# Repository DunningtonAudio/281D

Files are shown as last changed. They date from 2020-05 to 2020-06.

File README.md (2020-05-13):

# 281D
A quad function generator project

The 281D Quad Function Generator is designed to replicate the functionality of the Buchla 281 module using modern construction techniques and readily available parts. It is primarily based on the original circuit designed by Don Buchla, with the following additions/alterations:

* Improved input and mode selection circuitry – no requirement to “kick” the generators when selecting self cycle mode.
* All outputs are buffered, protecting the integrator core and passive end pulse generation from the effects of loading when stacked to multiple inputs.
* End pulse outputs are designed to allow stacking of multiple outputs to a single input without affecting cycling of individual generators, allowing the creation of complex/non-repeating/polyrhythmic pulse sequences. Unlike other solutions that simply add a diode in series with the output, the 281D end pulse outputs can drive a floating input low.
 
There are several build options to adjust the function of the module to a particular users requirements.

The repository contains:

* KiCad project files.
* Schematic and build/calibration notes as PDF files.
* Bill of Materials in ODS format.
* Interactive webpage for matching BOM items to PCB locations.

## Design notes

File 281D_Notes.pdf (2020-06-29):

281D Quad Function Generator

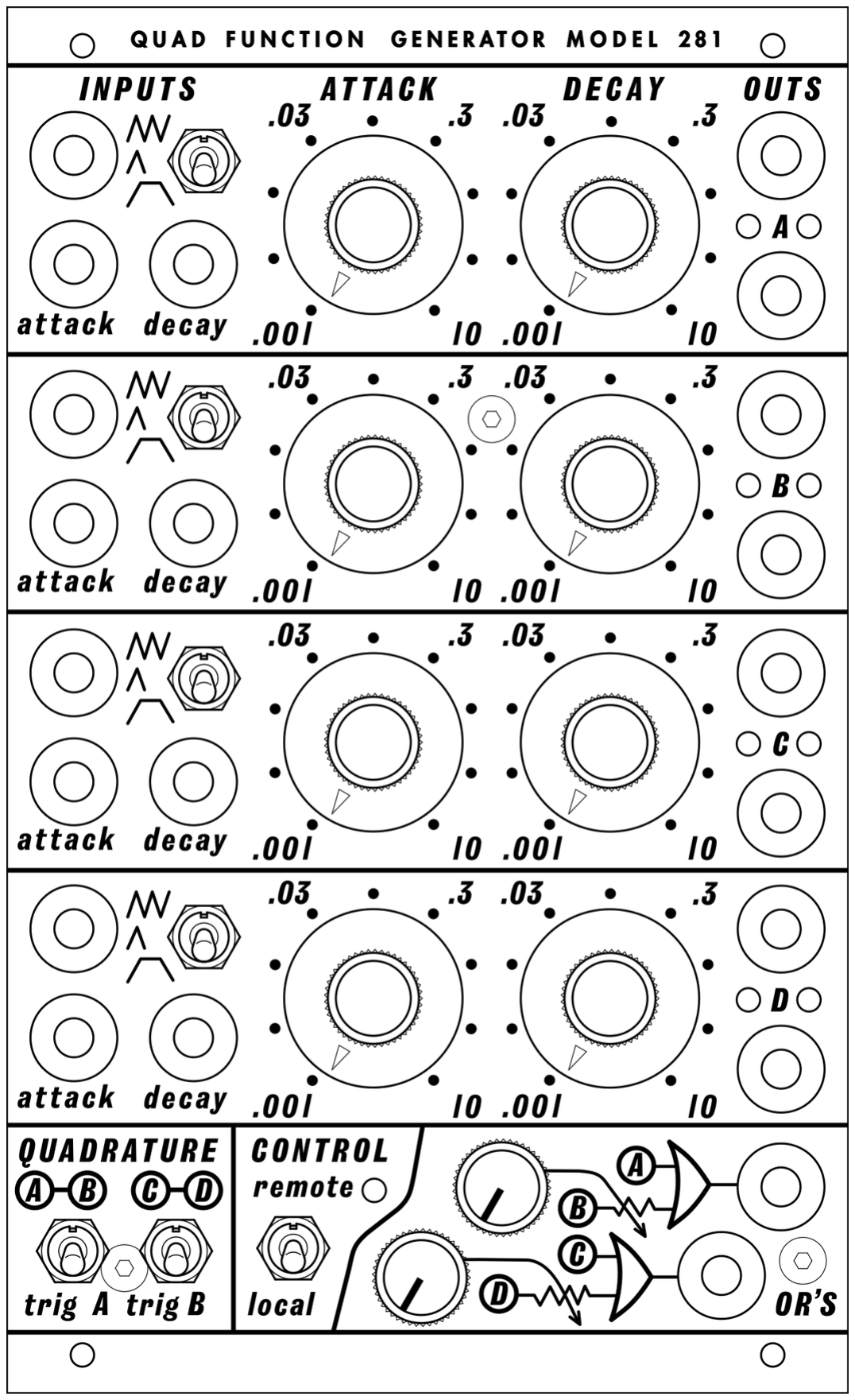
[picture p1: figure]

The 281D Quad Function Generator is designed to replicate the functionality of the Buchla 281 module using modern construction techniques and readily available parts. It is primarily based on the original circuit designed by Don Buchla, with the following additions/alterations:

- Improved input and mode selection circuitry – no requirement to “kick” the generators when selecting self cycle mode.
- All outputs are buffered, protecting the integrator core and passive end pulse generation circuit from the effects of loading when stacked to multiple inputs.
- End pulse outputs are designed to allow stacking of multiple outputs to a single input without affecting cycling of individual generators, allowing the creation of complex/non-repeating/polyrhythmic pulse sequences. Unlike other solutions that simply add a diode in series with the output, the 281D end pulse outputs can drive a floating input low.

Build Notes:

** The 281D is designed to be suitable for hand assembly, but it is not recommended as a “learn surface mount” starting point. You should at a minimum have a temperature controlled soldering iron with a reasonably fine point and good quality solder 0.5mm diameter or finer. Some form of magnification may be beneficial for placing/inspecting the SOT-363 packages. **

It is recommended that the circuit board is populated in the following order:

- SOT-363 packages (note polarity – these are not symmetrical!)
- SOT-23 packages
- SOIC packages
- 0805 passives
- Trimmer potentiometers
- Electrolytic capacitors
- Film capacitors C101,201,301,401 (Through hole pads are provided for hand assembly. If hand soldering the 2416 footprint SMT capacitors the minimum temperature/time possible should be used)
- Power wiring harness

Connectors should have their wire links attached and be mounted to the front panel, along with standoffs. Front panel potentiometers and switches can then be loosely fitted into the PCB and the panel and PCB brought together before gently tightening the potentiometer/switch fixing nuts and soldering the potentiometers and connector to PCB wires into place.

Modifications:

A standard build of the 281D uses the two-stage Buchla pulse to differentiate between the transient and sustain settings of the mode switch. If the module is to be used with standard gate signals, the following changes can be made:

- Omit or remove resistors R112,212,312,412
- Fit capacitors C199,299,399,499 (47nF 0805), diodes D199,299,399,499 (BAT54WS) and resistors R199,299,399,499 (4.7M 0805)

Calibration procedure:

Equipment required:
- Power supply delivering +/- 15V, current limit at 100mA and +12V, current limit at 20mA
- Oscilloscope (A DSO will make calibration easier)
1. Set front panel controls as follows:
- VR101/201/301/401 Attack – Fully CCW
- VR102/201/302/402 Decay – Fully CW
- VR203/403 OR Level – Fully CCW
- SW101/201/301/401 Mode – Centre/Transient
- SW102/302 Quadrature – Down
- SW1 Remote Enable – Down
2. Set all trimpots TR101,201,301,401 to halfway.
3. Apply power to the module and check for approx 85mA draw on the +15V rail and 70mA draw on the -15V rail. No current should be drawn from the 12V rail with the controls set as described above.
4. Switch function generator A into self cycle mode and monitor the CV output on the oscilloscope – it should be a 10V saw wave. Check the function of the output LED.
5. Adjust trimpot TR101 to set the fall time of the saw wave to 10 seconds.
6. Repeat steps 4 and 5 for function generators B/C/D, using trimpots TR201/301/401
7. Set front panel controls as follows:
- VR101/201/301/401 Attack – Fully CW
- VR102/201/302/402 Decay – Fully CCW
- VR203/403 OR Level – Fully CCW
- SW101/301 Mode – Up/Cycle
- SW201/401 Mode – Centre/Transient
- SW102,302 Quadrature – Up
- SW1 Remote Enable – Down
8. Check that all four quadrature LEDs are lit. The behaviour of the function generators should be as follows:
- A/C should slowly rise to their maximum amplitudes whilst B/D are idle
- Once A/C are at max, B/D will slowly rise to max
- Once B/D are at max, A/C will reset and begin to rise again, shortly followed by B/D also resetting
9. Set front panel controls as follows:
- VR101/301 Attack – Fully CW
- VR201/401 Attack – Fully CCW
- VR102/202/302/402 Decay – Fully CCW
- VR203/403 OR Level – Fully CW
- SW101/201/301/401 Mode – Up/Cycle
- SW102,302 Quadrature – Down
- SW1 Remote Enable – Down
10. Check the OR outputs on the oscilloscope – both should display a slow rise of the minimum voltage from 0V to 10V with rapidly oscillating peaks of 10V superimposed on top.
11. Check the function of the remote enable switch – the LED should illuminate in the centre and up positions of the switch and be extinguished in the down position.

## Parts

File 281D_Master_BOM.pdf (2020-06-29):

281D_Master

Reference | Quantity | Value | Footprint | Manufacturer | MPN | Supplier | Order Code | Description | Notes
PCB Mount
C102-103 C202-203 C302-303 C402-403 | 8 | 47n | C0805 | Yageo | CC0805KRX7R9BB473 | Mouser | 603-CC0805KRX7R9BB473 | X7R, 50V, 10%
C4 C6-8 C111-118 C211-213 C311-318 C411-413 | 26 | 100n | C0805 | Yageo | CC0805KRX7R9BB104 | Mouser | 603-CC0805KRX7R9BB104 | X7R, 50V, 10%
C101 C201 C301 C401 | 4 | 220n | C2416 | Panasonic | ECH-U1H224GX9 | Mouser | 667-ECH-U1H224GX9 | PPS, 50V, 2% | Alt. Fit 5.08mm THT box caps C_101, C_201, C_301, C_401
C1-3 C5 | 4 | 22u | CE5x5.8 | Panasonic | EEE-FK1V220AR | Mouser | 667-EEE-FK1V220AR | 35V, 20%, 105deg
D101 D107/207 D201 D301 D307/407 D401 | 6 | BAT54C | SOT-23-3 | On Semiconductor | BAT54CLT1G | Mouser | 863-BAT54CLT1G | Dual schottky diode common cathode
D102 D202 D302 D402 | 4 | SZMM3Z10VST1G | SOD-323 | On Semiconductor | SZMM3Z10VST1G | Mouser | 863-SZMM3Z10VST1G | Zener diode 10.2V 300mW
D103-104 D108-109 D203-204 D208 D303-304 D308-309 D403-404 D408 | 14 | BAT54WS | SOD-323 | Diodes Inc | BAT54WS-7-F | Mouser | 621-BAT54WS-F | Schottky diode 100mA
D1 D105 D205 D305 D405 | 5 | Red_3mm | 3mm LED THT | Wurth Elektronik | 151031SS04000 | Mouser | 710-151031SS04000 | LED red 3mm 635nm 160mcd
D106 D206 D306 D406 | 4 | Yel_3mm | 3mm LED THT | Wurth Elektronik | 151031YS06000 | Mouser | 710-151031YS06000 | LED yellow 3mm 590nm 110mcd
L1 L2 L3 | 3 | 10u | L0805 | Taiyo Yuden | LBC2012T100K | Mouser | 963-LBC2012T100K | 1.2R, 200mA, 10%
Q1 Q103 Q203 Q303 Q403 | 5 | MMBT3904 | SOT-23-3 | On Semiconductor | MMBT3904LT1G | Mouser | 863-MMBT3904LT1G | NPN
Q101 Q201 Q301 Q401 | 4 | DMMT3906W | SOT-363 | Diodes Inc | DMMT3906W-7-F | Mouser | 621-DMMT3906W-F | Dual Matched PNP | Note polarity – these are not symmetrical!
Q102 Q202 Q302 Q402 | 4 | MMBFJ201 | SOT-23-3 | On Semiconductor | MMBFJ201 | Mouser | 512-MMBFJ201 | N-Channel JFET
R123-124 R127 R223-224 R227 R323-324 R327 R423-424 R427 | 12 | 680R | R0805 | Yageo | RC0805FR-07680RL | Mouser | 603-RC0805FR-07680RL | 150V, 125mW, 1%, 100PPM
R110 R116 R144 R147 R153 R210 R216 R244 R247 R310 R316 R344 R347 R353 R410 R416 R444 R447 | 18 | 1k | R0805 | Yageo | RC0805FR-071KL | Mouser | 603-RC0805FR-071KL | 150V, 125mW, 1%, 100PPM
R102 R119 R129-132 R202 R219 R229-232 R302 R319 R329-332 R402 R419 R429-432 | 24 | 4k7 | R0805 | Yageo | RC0805FR-074K7L | Mouser | 603-RC0805FR-074K7L | 150V, 125mW, 1%, 100PPM
R106 R148 R206 R306 R348 R406 | 6 | 5k6 | R0805 | Yageo | RC0805FR-075K6L | Mouser | 603-RC0805FR-075K6L | 150V, 125mW, 1%, 100PPM
R1 R134 R234 R334 R434 | 5 | 6k8 | R0805 | Yageo | RC0805FR-076K8L | Mouser | 603-RC0805FR-076K8L | 150V, 125mW, 1%, 100PPM
R126 R136 R143 R146 R152 R226 R236 R243 R246 R326 R336 R343 R346 R352 R426 R436 R443 R446 | 18 | 10k | R0805 | Yageo | RC0805FR-0710KL | Mouser | 603-RC0805FR-0710KL | 150V, 125mW, 1%, 100PPM
R142 R145 R151 R242 R245 R342 R345 R351 R442 R445 | 10 | 11k | R0805 | Yageo | RC0805FR-0711KL | Mouser | 603-RC0805FR-0711KL | 150V, 125mW, 1%, 100PPM
R103 R203 R303 R403 | 4 | 15k | R0805 | Yageo | RC0805FR-0715KL | Mouser | 603-RC0805FR-0715KL | 150V, 125mW, 1%, 100PPM
R2 R128 R133 R140 R228 R233 R240 R328 R333 R340 R428 R433 R440 | 13 | 22k | R0805 | Yageo | RC0805FR-0722KL | Mouser | 603-RC0805FR-0722KL | 150V, 125mW, 1%, 100PPM
R104 R108-109 R113-114 R121 R125 R149 R204 R208-209 R213-214 R221 R225 R304 R308-309 R313-314 R321 R325 R349 R404 R408-409 R413-414 R421 R425 | 30 | 47k | R0805 | Yageo | RC0805FR-0747KL | Mouser | 603-RC0805FR-0747KL | 150V, 125mW, 1%, 100PPM
R105 R107 R115 R117 R135 R205 R207 R215 R217 R235 R305 R307 R315 R317 R335 R405 R407 R415 R417 R435 | 20 | 49k9 | R0805 | Yageo | RC0805FR-0749K9L | Mouser | 603-RC0805FR-0749K9L | 150V, 125mW, 1%, 100PPM
R101 R111-112 R138 R141 R150 R201 R211-212 R238 R241 R301 R311-312 R338 R341 R350 R401 R411-412 R438 R441 | 22 | 100k | R0805 | Yageo | RC0805FR-07100KL | Mouser | 603-RC0805FR-07100KL | 150V, 125mW, 1%, 100PPM
R122 R222 R322 R422 | 4 | 150k | R0805 | Yageo | RC0805FR-07150KL | Mouser | 603-RC0805FR-07150KL | 150V, 125mW, 1%, 100PPM
R137 R237 R337 R437 | 4 | 470k | R0805 | Yageo | RC0805FR-07470KL | Mouser | 603-RC0805FR-07470KL | 150V, 125mW, 1%, 100PPM
R139 R239 R339 R439 | 4 | 1M | R0805 | Yageo | RC0805FR-071ML | Mouser | 603-RC0805FR-071ML | 150V, 125mW, 1%, 100PPM
R118 R120 R218 R220 R318 R320 R418 R420 | 8 | 4M7 | R0805 | Yageo | RC0805FR-074M7L | Mouser | 603-RC0805FR-074M7L | 150V, 125mW, 1%, 100PPM
SW1 SW101 SW201 SW301 SW401 | 5 | SPDT_ON-OFF-ON | M201X | NKK | M2013SS1W01 | Mouser | 633-M201301 | Toggle switch SPDT On-Off-On
SW102, SW302, | 2 | SPDT_ON-ON | M201X | NKK | M2012SS1W01 | Mouser | 633-M201201 | Toggle switch SPDT On-On
TR101, TR201, TR301, TR401, | 4 | 50k | 3314J | Bourns | 3314J-1-503E | Mouser | 652-3314J-1-503E | 500V,250mW, 20%, 100PPM
U1, | 1 | L78L10 | SOT-89 | ST Microelectronics | L78L10ACUTR | Mouser | 511-L78L10ACU | Linear voltage reg 10V 100mA
U2, | 1 | TL072 | SOIC08 | Texas Instruments | TL072IDR | Mouser | 595-TL072IDR | Dual op-amp FET input
U101, U201, U105/205, U301, U401, U305/405, | 6 | TL074 | SOIC14 | Texas Instruments | TL074IDR | Mouser | 595-TL074IDR | Quad op-amp FET input
U102, U202, U302, U402, | 4 | CD4001 | SOIC14 | Texas Instruments | CD4001BM96 | Mouser | 595-CD4001BM96 | Quad NOR gate 2 input
U103/203, U303/403, | 2 | CD4066 | SOIC14 | Texas Instruments | CD4066BM96 | Mouser | 595-CD4066BM96 | Quad analogue switch SPST
U104/204, U304/404, | 2 | LM13700 | SOIC16 | Texas Instruments | LM13700MX/NOPB | Mouser | 926-LM13700MX/NOPB | Dual transconductance amplifier
VR101-102 VR201-202 VR301-302 VR401-402 | 8 | 10k Linear | RV16AF-41-(L)R1-XXX | Alpha | RV16AF-41-15R1-103B | Small Bear | 1011 B10K | 16mm RA PCB mount potentiometer
VR203 VR403 | 2 | 100k Linear | RD901F-40-00D | Alpha | RD901F-40-15R1-104B | Small Bear | 1012A B100K | 9mm RA PCB mount potentiometer
| 8 | | | Alpha | M7x0.75 | Small Bear | 1018 | Toothed washer for 16mm potentiometer | Fit between potentiometer body and panel
| 8 | | | Alpha | | Small Bear | 1011AM | Dust cover for 16mm potentiometer | Fit on all 16mm potentiometers

281D_Master

Reference | Quantity | Value | Footprint | Manufacturer | MPN | Supplier | Order Code | Description | Notes
Panel Mount
J101 J201 J301 J401 | 4 | Pulse inputs | Johnson | 108-0906-001 | Mouser | 530-108-0906-1 | Orange banana jack
J102-103 J202-203 J302-J303 J402-J403 | 8 | CV inputs | Johnson | 108-0903-001 | Mouser | 530-108-0903-1 | Black banana jack
J104 J204 J304 J404 | 4 | Pulse outputs | Johnson | 108-0902-001 | Mouser | 530-108-0902-1 | Red banana jack
J105-106 J205 J305-306 J405 | 6 | CV outputs | Johnson | 108-0910-001 | Mouser | 530-108-0910-1 | Blue banana jack
24awg wire black 25mm length | 8 | | Alpha Wire | 892419 BK005 | Mouser | 602-892419-100-02 | Wiring to CV inputs | Strip 4mm each end. Order code is for 30.5m reel
24awg wire orange 25mm length | 4 | | Alpha Wire | 892419 OR005 | Mouser | 602-892419-100-08 | Wiring to pulse inputs | Strip 4mm each end. Order code is for 30.5m reel
24awg wire red 25mm length | 4 | | Alpha Wire | 892419 RD005 | Mouser | 602-892419-100-03 | Wiring to pulse outputs | Strip 4mm each end. Order code is for 30.5m reel
24awg wire blue 25mm length | 6 | | Alpha Wire | 892419 BL005 | Mouser | 602-892419-100-06 | Wiring to CV outputs | Strip 4mm each end. Order code is for 30.5m reel
Hardware & Misc
PCB | 1 | | Dunnington Audio | | thebeast.co.uk | http://thebeast.co.uk/?product | Printed circuit board
Front panel | 1 | | The Beast | | thebeast.co.uk | http://thebeast.co.uk/?product=Front panel
M3x14mm F-F Standoff | 3 | | Harwin | R30-1001402 | Mouser | 855-R30-1001402
M3x6mm Pozi CSK | 3 | | RS Pro | | RS | 528-946 | | Panel to standoff fixing
M3x6mm Pozi Pan SEMS | 3 | | RS Pro | | RS | 279-149 | | PCB to standoff fixing
M3 Toothed Washer | 3 | | RS Pro | | RS | 526-574 | | Fit between standoffs and panel
Small Skirted Knob Blue | 8 | | Rogan | RB-67-0-SK-7-M | Thonk | https://www.thonk.co.uk/shop/r | | Fit on all 16mm potentiometers
Small Unskirted Knob Blue | 2 | | Rogan | RB-67-0-ML | Thonk | https://www.thonk.co.uk/shop/r | | Fit on all 9mm potentiometers
Switch Cap Red | 4 | | Mountain Switch | 10TB001 | Mouser | 10TB001 | | Fit on SW101, SW201, SW301, SW401
Switch Cap Yellow | 2 | | Mountain Switch | 10TB005 | Mouser | 10TB005 | | Fit on SW102, SW302
Switch Cap White | 1 | | Mountain Switch | 10TB003 | Mouser | 10TB003 | | Fit on SW1
J1 | 1 | Power | EDAC | 306-010-500-102 | Mouser | 587-306-50-010 | 10P edge connector, 3.96mm
| 1 | | EDAC | 338-240-328 | Mouser | 587-338-240-328 | Polarizing key | Fit in position 7 of power EDAC
20awg wire black 350mm length | 1 | Q | Alpha Wire | 892019 BK005 | Mouser | 602-892019-100-02 | | EDAC position 1. Order code is for 30.5m reel.
20awg wire white 350mm length | 1 | -15V | Alpha Wire | 892019 WH005 | Mouser | 602-892019-100-01 | | EDAC position 2. Order code is for 30.5m reel.
20awg wire red 350mm length | 1 | +15V | Alpha Wire | 892019 RD005 | Mouser | 602-892019-100-03 | | EDAC position 3. Order code is for 30.5m reel.
20awg wire green 350mm length | 1 | +12V | Alpha Wire | 892019 GR005 | Mouser | 602-892019-100-04 | | EDAC position 4. Order code is for 30.5m reel.
Expandable Sleeving 3mm 300mm | 1 | | Alpha Wire | GRP1301/8 BK007 | Mouser | 602-130018-50BK | | Fit over power cabling
Heatshrink 6.35mm 40mm length | 2 | | Alpha Wire | FIT221V1/4 BK103 | Mouser | 602-221V014-4 | | Fit at each end of expandable sleeving
Heatshrink 3.18mm 12mm length | 4 | | Alpha Wire | FIT221V1/8 BK103 | Mouser | 602-221V018-4 | | Fit over terminated EDAC contacts
Cable ties | 2 | | Panduit | PLT.7M-M | Mouser | 644-PLT.7M-M | | Secure power cabling to PCB and EDAC

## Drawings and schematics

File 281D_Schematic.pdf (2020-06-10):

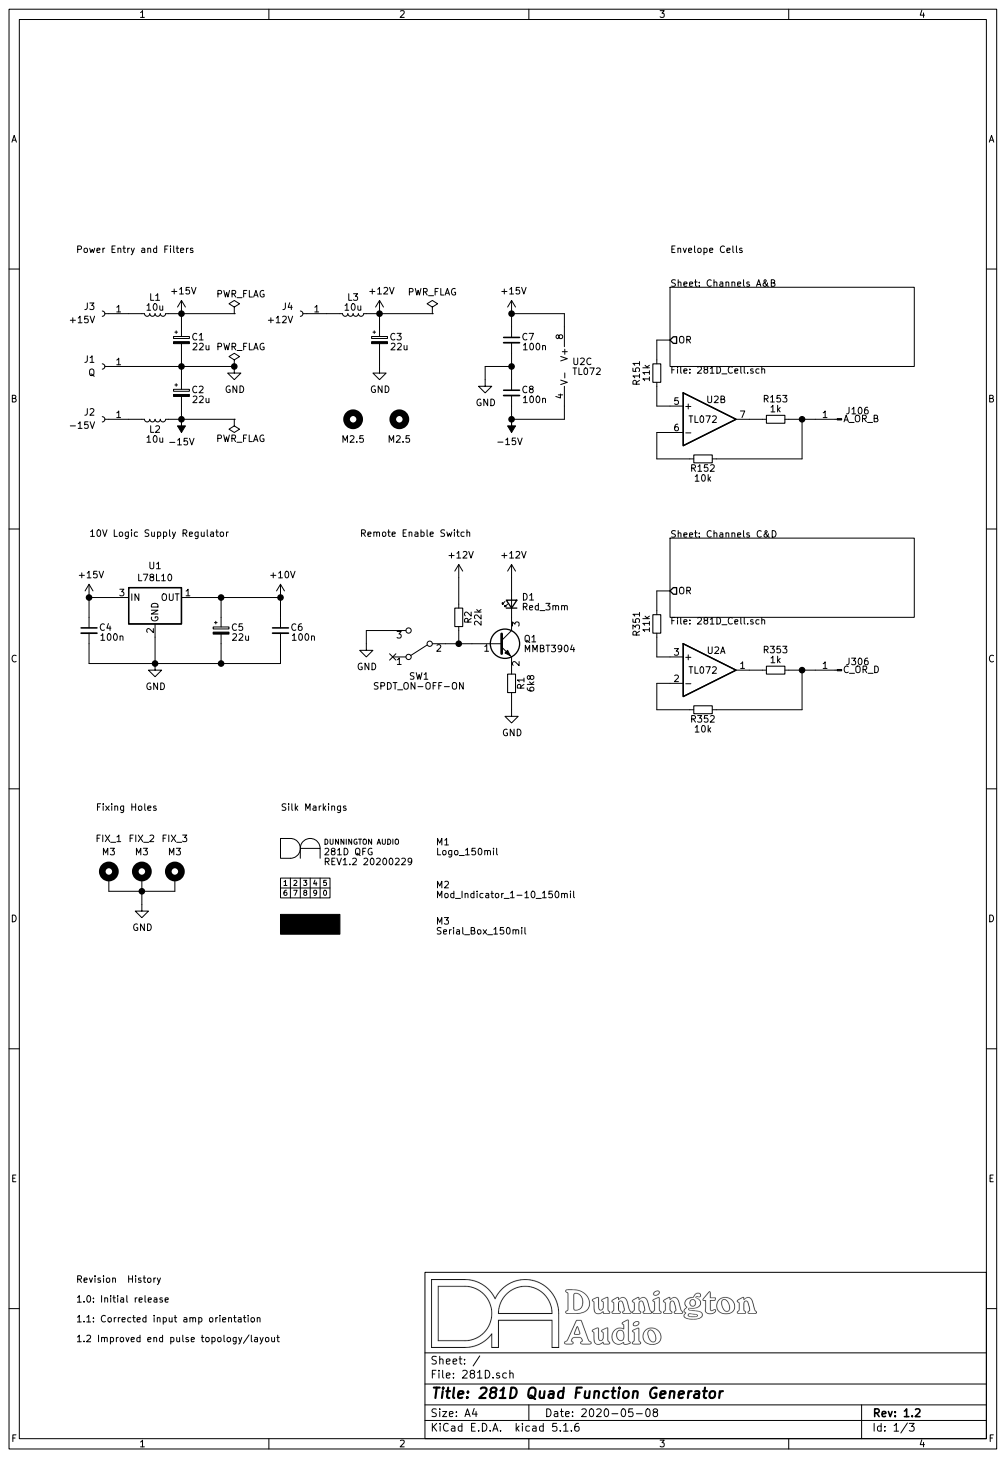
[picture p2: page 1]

1.0: Initial release Revision History

1.1: Corrected input amp orientation
1.2 Improved end pulse topology/layout

Id: 1/3 Title: 281D Quad Function Generator File: 281D.sch Sheet: /

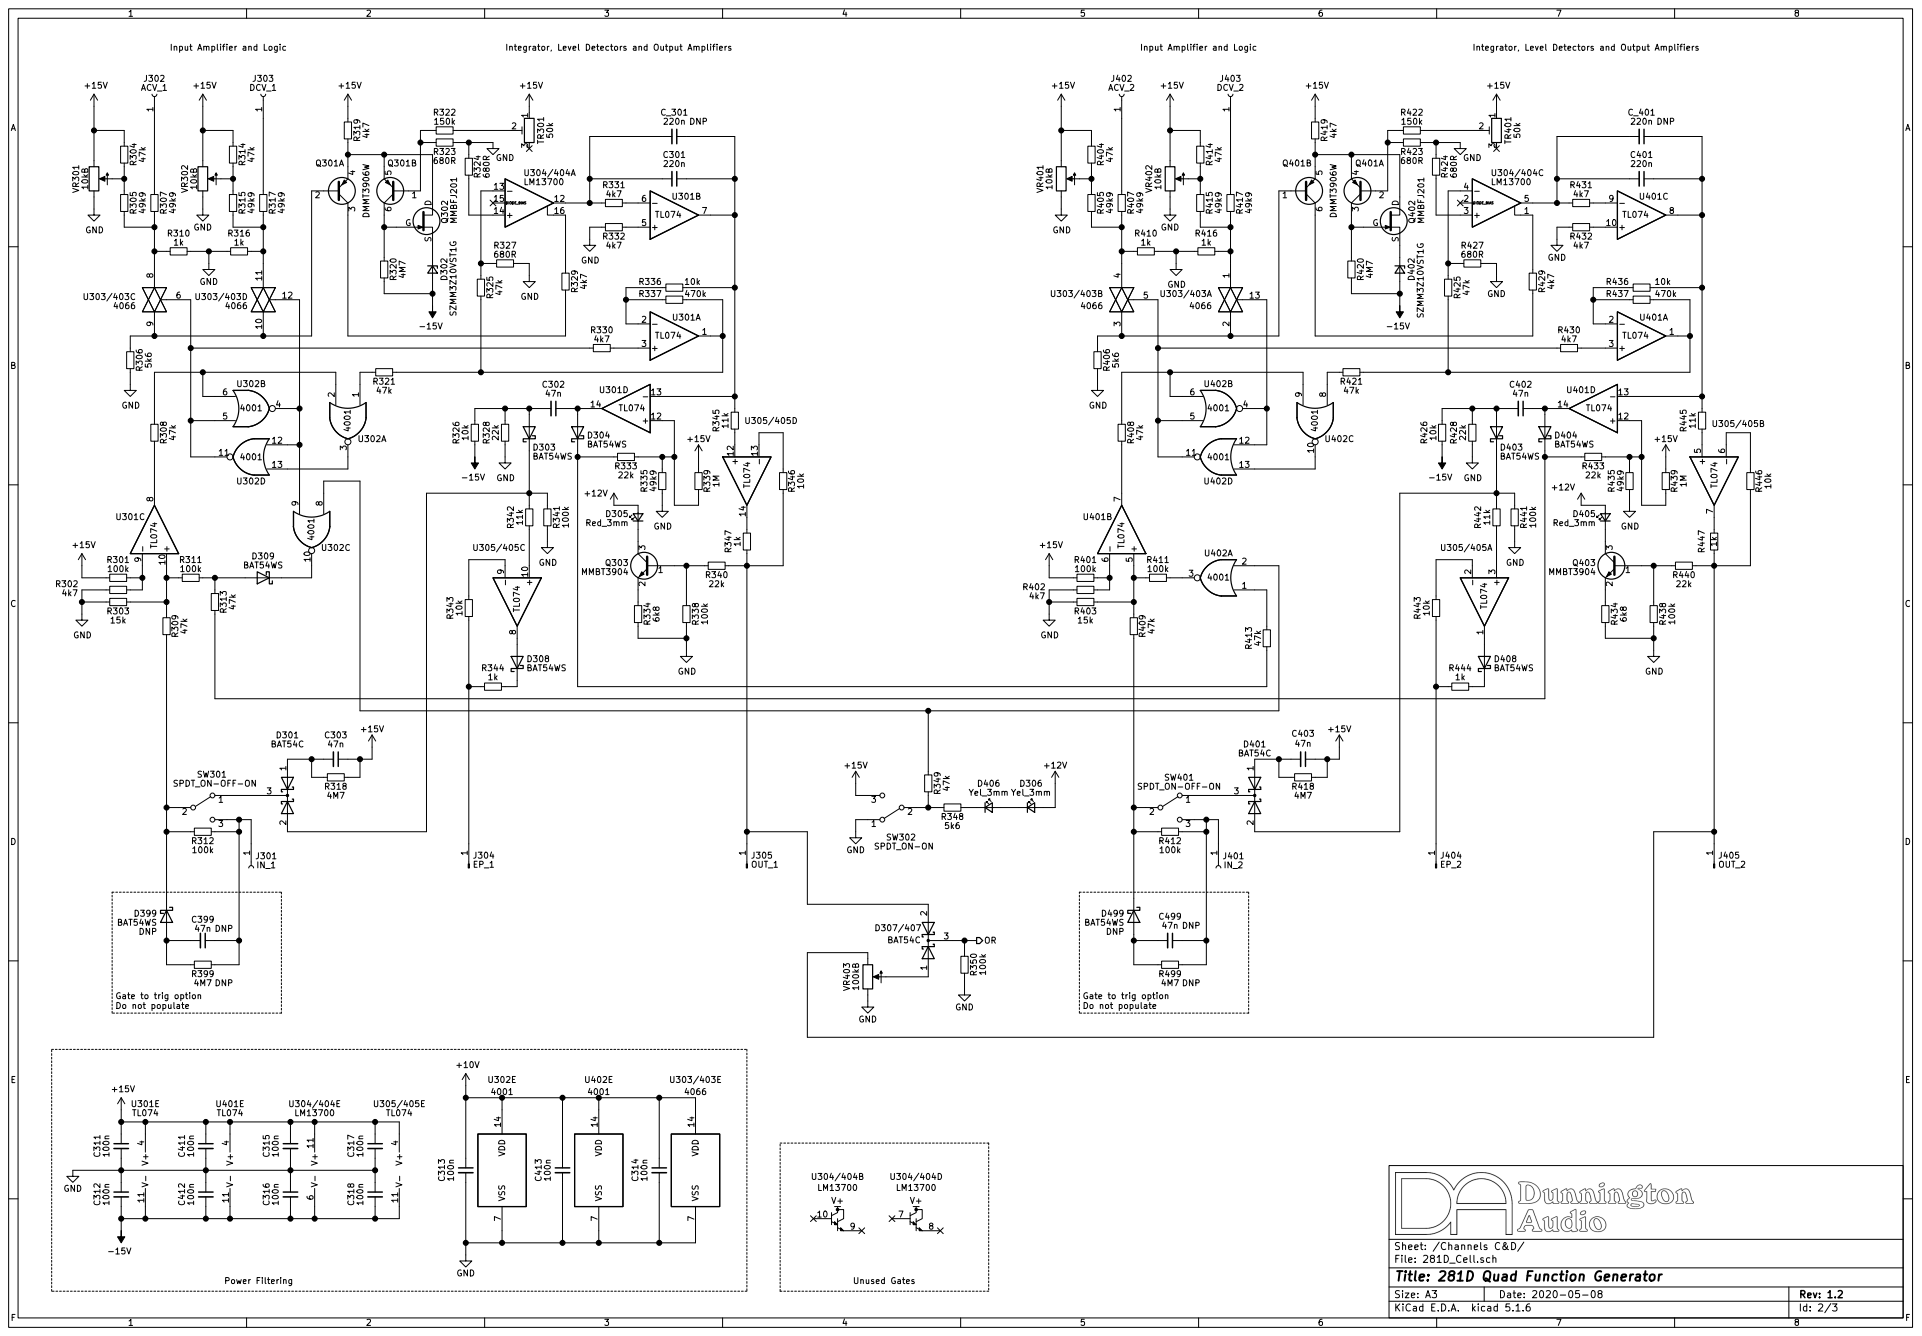
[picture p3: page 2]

Input Amplifier and Logic

Integrator, Level Detectors and Output Amplifiers

Gate to trig option

Do not populate

File: 281D_Cell.sch Sheet: /Channels C&D/
Id: 2/3 Title: 281D Quad Function Generator

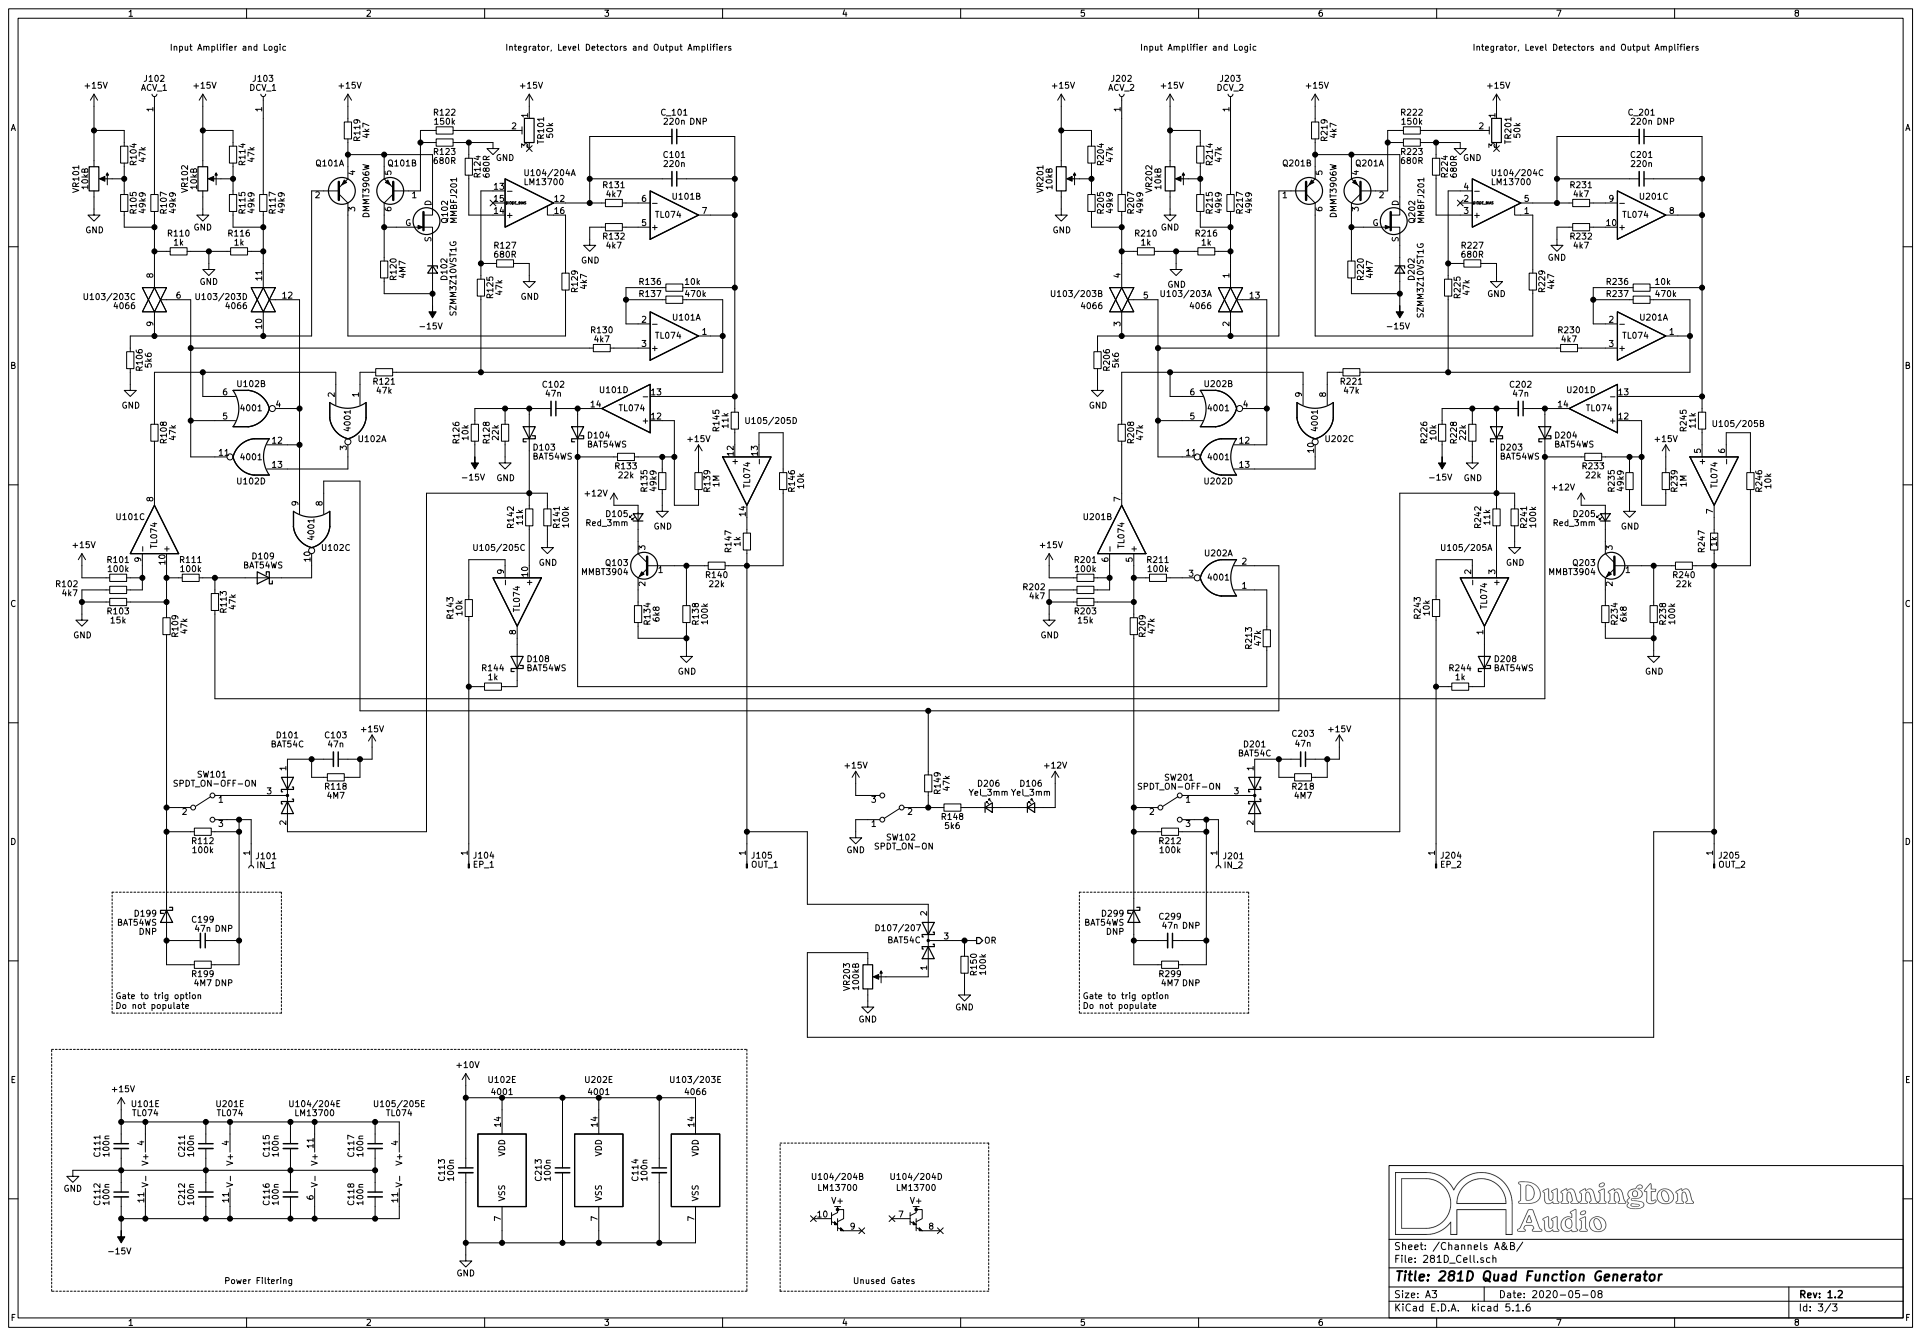
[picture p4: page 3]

Input Amplifier and Logic

Integrator, Level Detectors and Output Amplifiers

Gate to trig option

Do not populate

File: 281D_Cell.sch Sheet: /Channels A&B/
Id: 3/3 Title: 281D Quad Function Generator

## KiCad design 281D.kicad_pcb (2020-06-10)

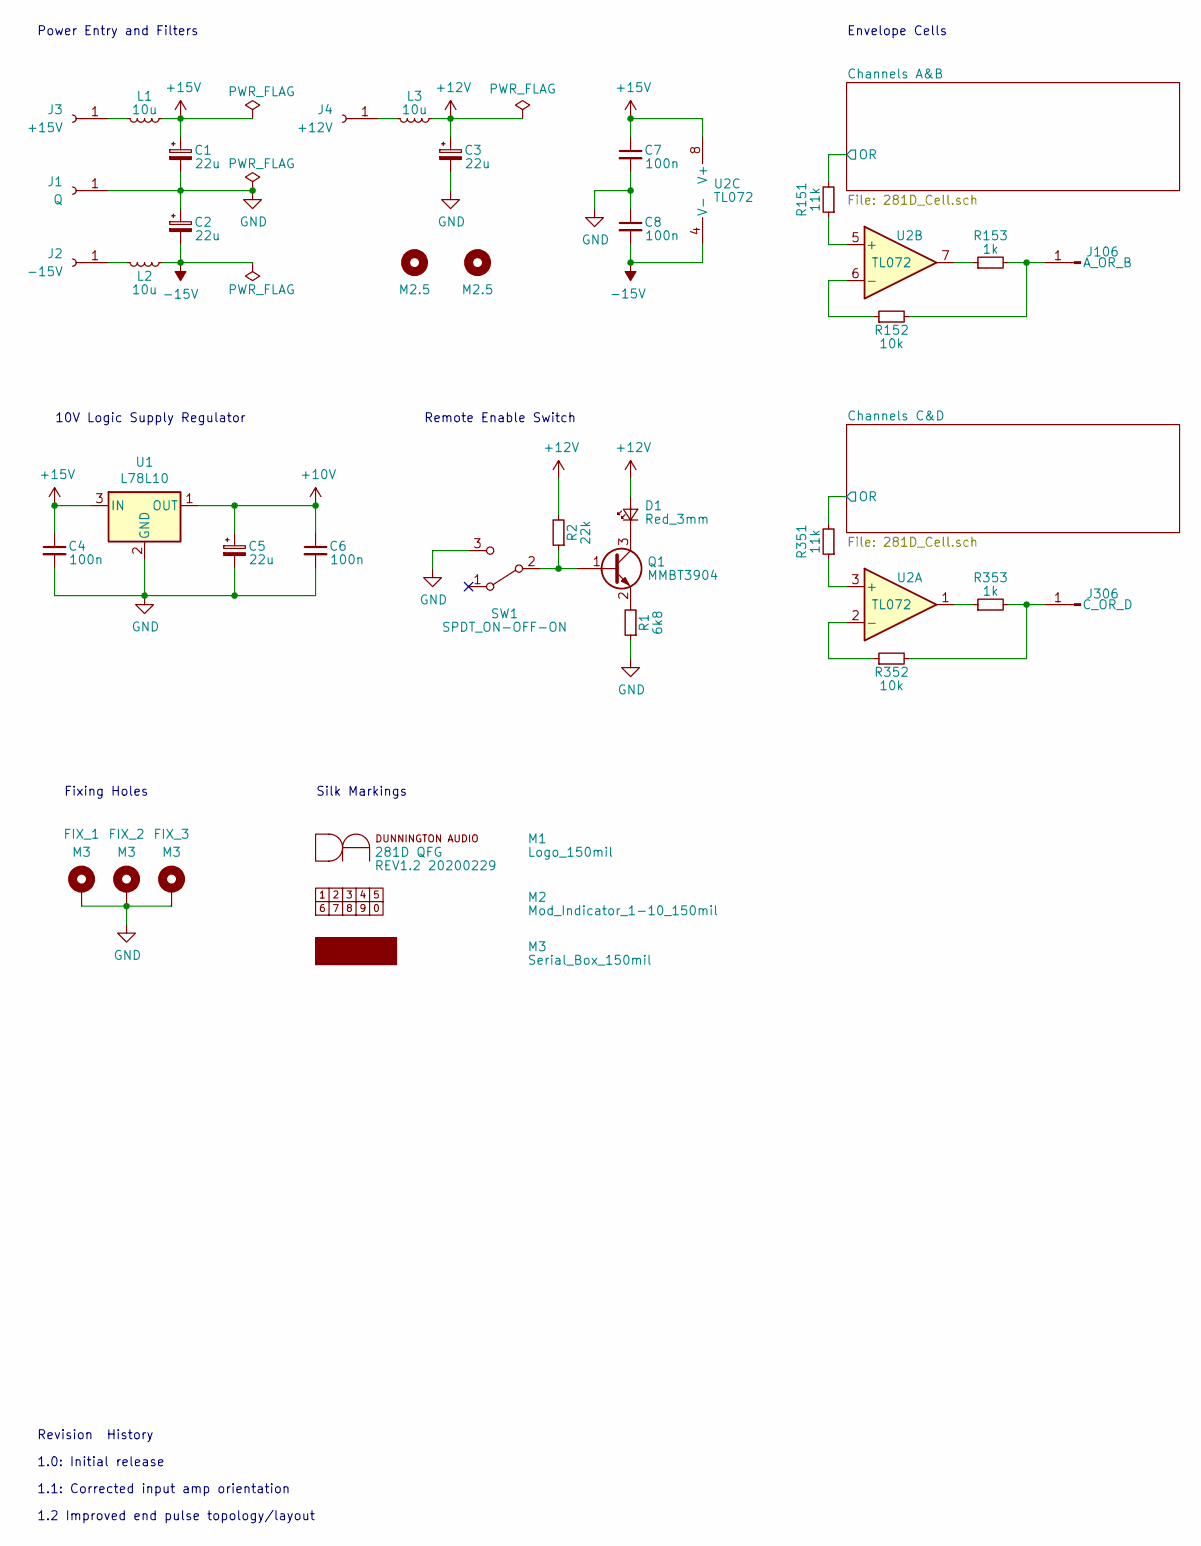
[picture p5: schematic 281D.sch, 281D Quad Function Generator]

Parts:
C1, C2, C3, C5: 22u; CP_Elec_5x5.3
C4, C6, C7, C8: 100n; C_0805_2012Metric
D1: Red_3mm; LED_D3.0mm
FIX_1, FIX_2, FIX_3: M3; MountingHole_3.2mm_M3_Pad_Via
H101, H102: M2.5; MountingHole_2.5mm
J1: Q; SolderWirePad_1x01_Drill1.2mm
J2: -15V; SolderWirePad_1x01_Drill1.2mm
J3: +15V; SolderWirePad_1x01_Drill1.2mm
J4: +12V; SolderWirePad_1x01_Drill1.2mm
J106, J306: 108-0910-001; Johnson_108-09XX-001
L1, L2, L3: 10u; L_0805_2012Metric
M1: Logo_150mil
M2: Mod_Indicator_1-10_150mil
M3: Serial_Box_150mil
Q1: MMBT3904; SOT-23
R1: 6k8; R_0805_2012Metric
R2: 22k; R_0805_2012Metric
R151, R351: 11k; R_0805_2012Metric
R152, R352: 10k; R_0805_2012Metric
R153, R353: 1k; R_0805_2012Metric
SW1: SPDT_ON-OFF-ON; M201xSS1x01
U1: L78L10; SOT-89-3
U2: TL072; SOIC-8_3.9x4.9mm_P1.27mm

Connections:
+10V: C5.1, C6.1, U1.1 (OUT); also elsewhere on the board
+12V: C3.1, D1.2 (A), L3.1, R2.2; also elsewhere on the board
+15V: C1.1, C4.1, C7.1, L1.1, U1.3 (IN), U2.8 (V+); also elsewhere on the board
-15V: C2.2, C8.2, L2.1, U2.4 (V-); also elsewhere on the board
/Channels A&B/OR: R151.2; also elsewhere on the board
/Channels C&D/OR: R351.2; also elsewhere on the board
GND: C1.2, C2.1, C3.2, C4.2, C5.2, C6.2, C7.2, C8.1, FIX_1.1, FIX_2.1, FIX_3.1, J1.1, R1.1, SW1.3 (C), U1.2 (GND); also elsewhere on the board
unnamed: D1.1 (K), Q1.3 (C)
unnamed: J2.1, L2.2
unnamed: J3.1, L1.2
unnamed: J4.1, L3.2
unnamed: J106.1, R152.2, R153.2
unnamed: J306.1, R352.2, R353.2
unnamed: Q1.1 (B), R2.1, SW1.2 (B)
unnamed: Q1.2 (E), R1.2
unnamed: R151.1, U2.5 (+)
unnamed: R152.1, U2.6 (-)
unnamed: R153.1, U2.7
unnamed: R351.1, U2.3 (+)
unnamed: R352.1, U2.2 (-)
unnamed: R353.1, U2.1

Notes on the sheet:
Envelope Cells
Power Entry and Filters
10V Logic Supply Regulator
Remote Enable Switch
Fixing Holes
Revision History
1.0: Initial release
1.1: Corrected input amp orientation
1.2 Improved end pulse topology/layout
Silk Markings

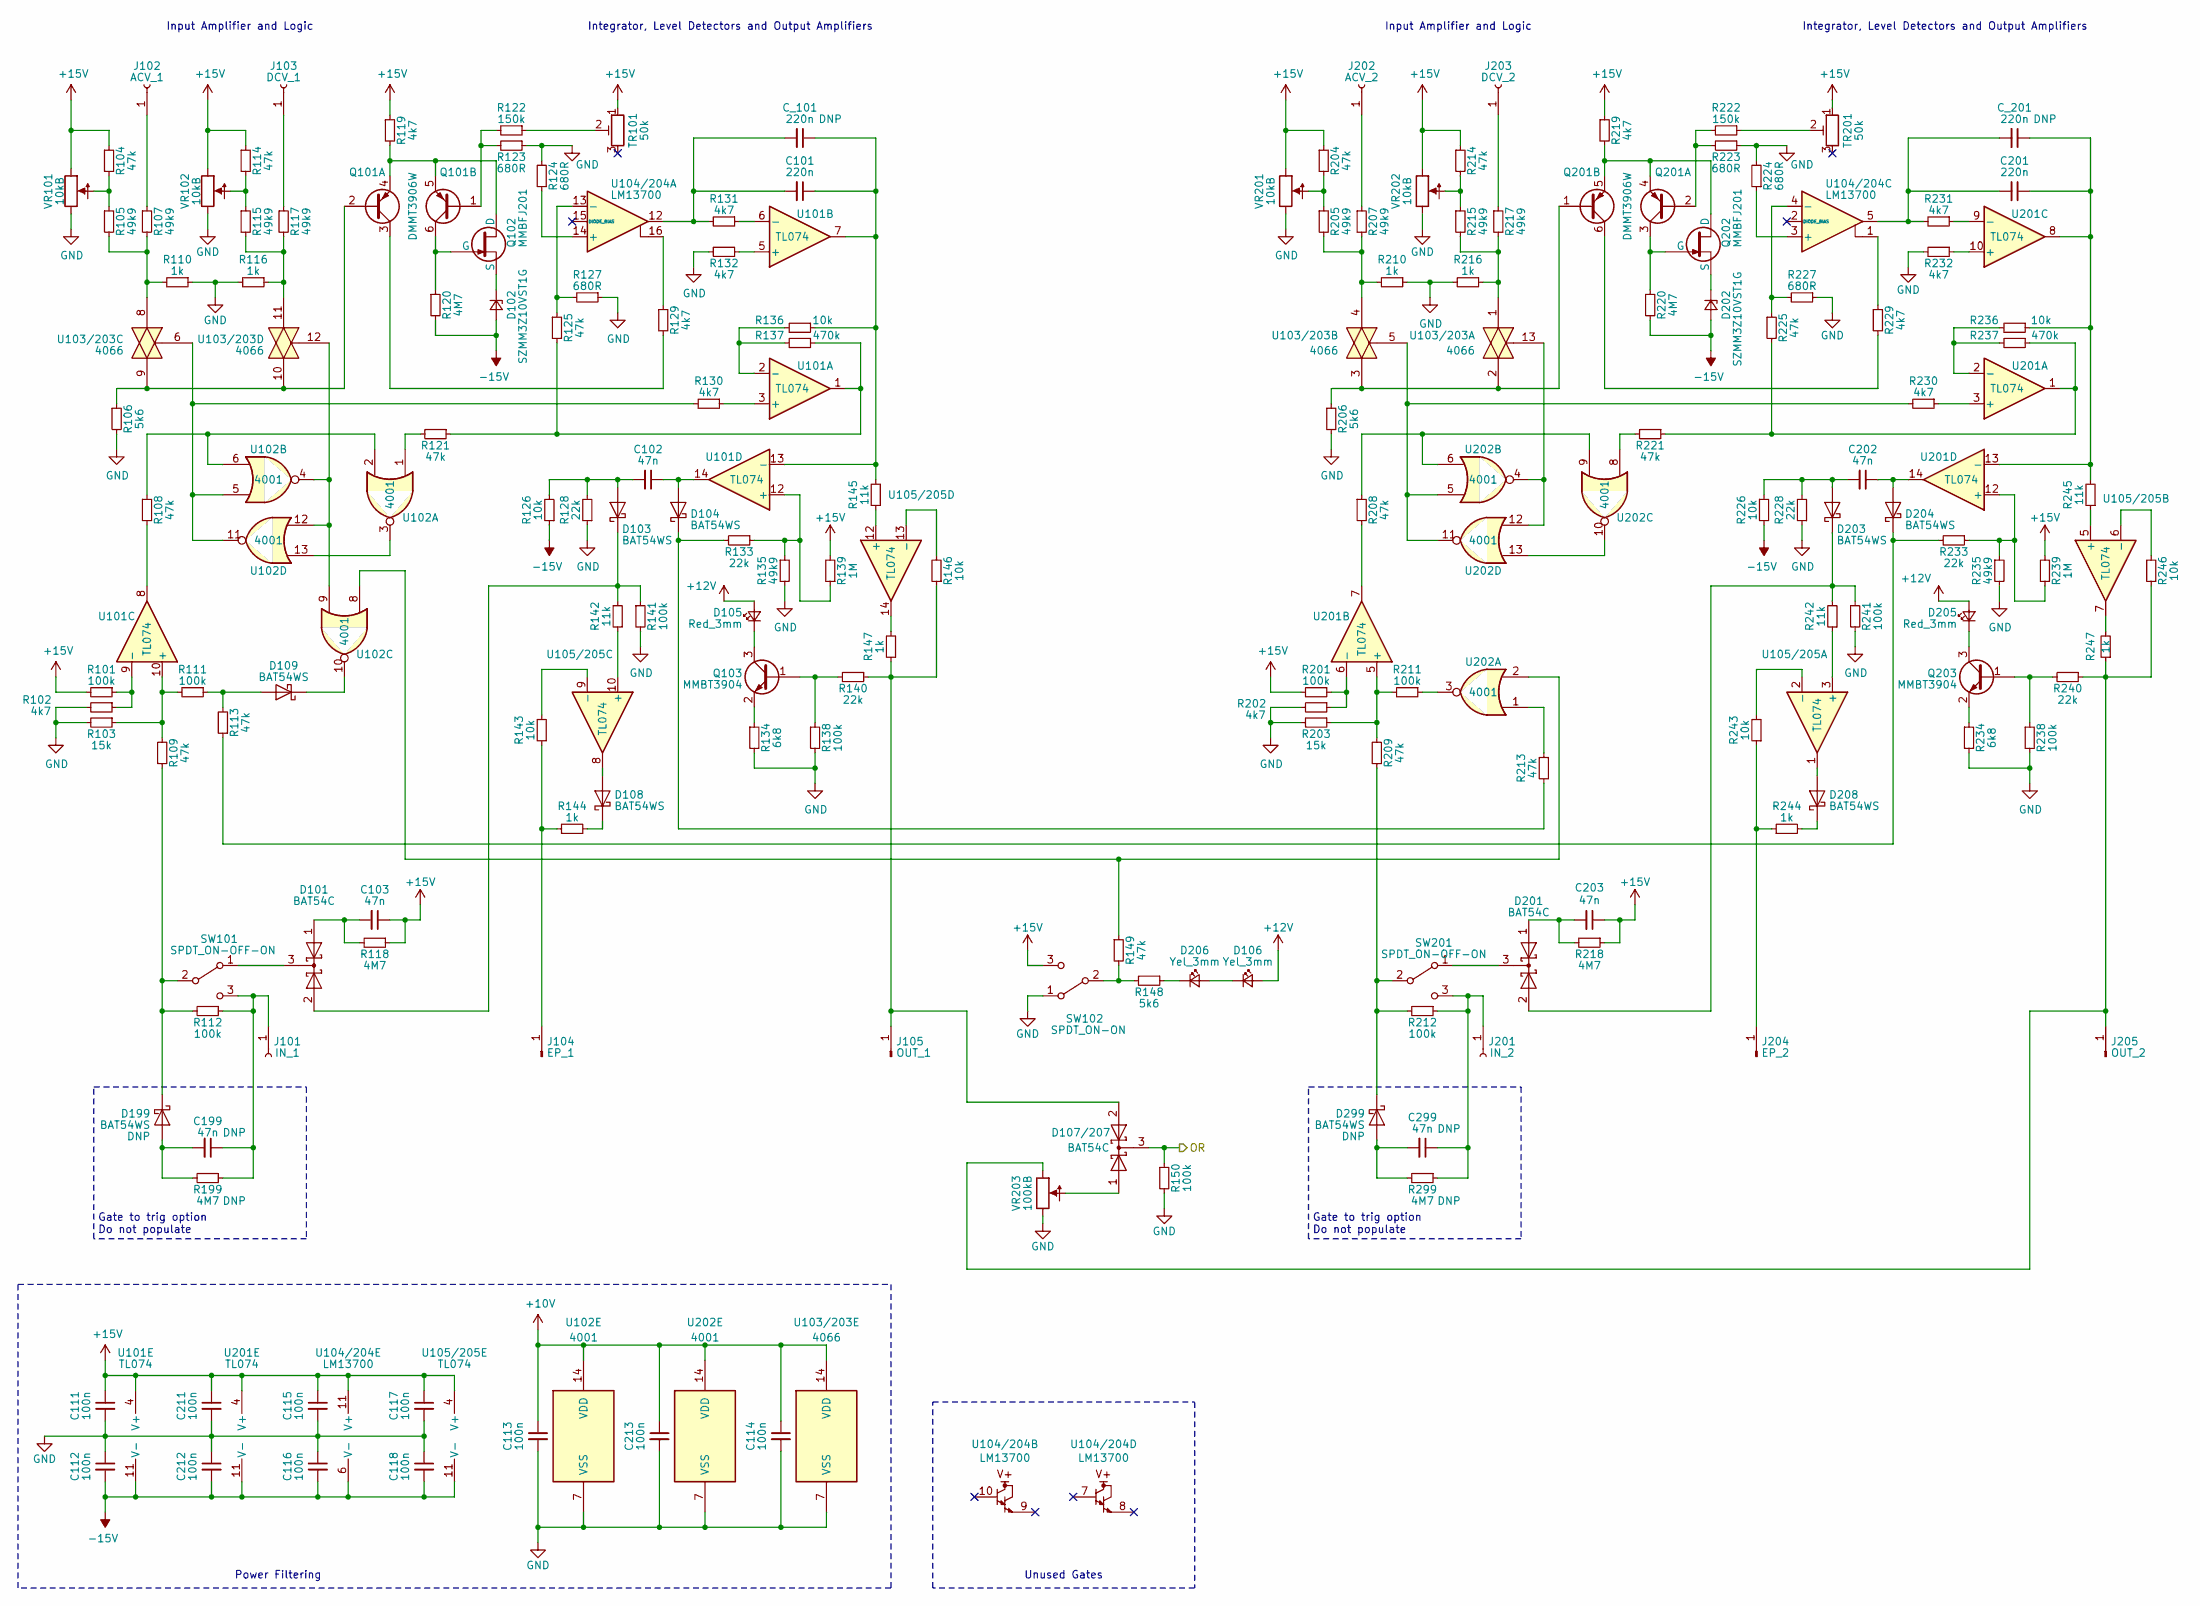
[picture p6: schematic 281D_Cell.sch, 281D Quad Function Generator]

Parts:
C101, C201: 220n; C_2416_6041Metric
C102, C103, C199, C202, C203, C299: 47n; C_0805_2012Metric
C111, C112, C113, C114, C115, C116, C117, C118, C211, C212, C213: 100n; C_0805_2012Metric
C_101, C_201: 220n; C_Rect_L7.0mm_W2.5mm_P5.00mm
D101, D107/207, D201: BAT54C; SOT-23
D102, D202: SZMM3Z10VST1G; D_SOD-323
D103, D104, D108, D109, D199, D203, D204, D208, D299: BAT54WS; D_SOD-323
D105, D205: Red_3mm; LED_D3.0mm
D106, D206: Yel_3mm; LED_D3.0mm
J101, J201: 108-0906-001; Johnson_108-09XX-001
J102, J103, J202, J203: 108-0903-001; Johnson_108-09XX-001
J104, J204: 108-0902-001; Johnson_108-09XX-001
J105, J205: 108-0910-001; Johnson_108-09XX-001
Q101, Q201: DMMT3906W; SOT-363_SC-70-6
Q102, Q202: MMBFJ201; SOT-23
Q103, Q203: MMBT3904; SOT-23
R101, R111, R112, R138, R141, R150, R201, R211, R212, R238, R241: 100k; R_0805_2012Metric
R102, R119, R129, R130, R131, R132, R202, R219, R229, R230, R231, R232: 4k7; R_0805_2012Metric
R103, R203: 15k; R_0805_2012Metric
R104, R108, R109, R113, R114, R121, R125, R149, R204, R208, R209, R213, R214, R221, R225: 47k; R_0805_2012Metric
R105, R107, R115, R117, R135, R205, R207, R215, R217, R235: 49k9; R_0805_2012Metric
R106, R148, R206: 5k6; R_0805_2012Metric
R110, R116, R144, R147, R210, R216, R244, R247: 1k; R_0805_2012Metric
R118, R120, R199, R218, R220, R299: 4M7; R_0805_2012Metric
R122, R222: 150k; R_0805_2012Metric
R123, R124, R127, R223, R224, R227: 680R; R_0805_2012Metric
R126, R136, R143, R146, R226, R236, R243, R246: 10k; R_0805_2012Metric
R128, R133, R140, R228, R233, R240: 22k; R_0805_2012Metric
R134, R234: 6k8; R_0805_2012Metric
R137, R237: 470k; R_0805_2012Metric
R139, R239: 1M; R_0805_2012Metric
R142, R145, R242, R245: 11k; R_0805_2012Metric
SW101, SW201: SPDT_ON-OFF-ON; M201xSS1x01
SW102: SPDT_ON-ON; M201xSS1x01
TR101, TR201: 50k; Potentiometer_Bourns_3314J_Vertical
U101, U105/205, U201: TL074; SOIC-14_3.9x8.7mm_P1.27mm
U102, U202: 4001; SOIC-14_3.9x8.7mm_P1.27mm
U103/203: 4066; SOIC-14_3.9x8.7mm_P1.27mm
U104/204: LM13700; SOIC-16_3.9x9.9mm_P1.27mm
VR101, VR102, VR201, VR202: 10kB; RV16AF-41-(L)R1-XXX
VR203: 100kB; RD901F-40-00D

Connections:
+10V: C113.1, C114.1, C213.1, U102.14 (VDD), U103/203.14 (VDD), U202.14 (VDD); also elsewhere on the board
+12V: D105.2 (A), D106.2 (A), D205.2 (A); also elsewhere on the board
+15V: C103.1, C111.1, C115.1, C117.1, C203.1, C211.1, R101.2, R104.1, R114.1, R118.1, R119.1, R139.2, R201.2, R204.1, R214.1, R218.1, R219.1, R239.2, SW102.3 (C), TR101.1, TR201.1, U101.4 (V+), U104/204.11 (V+), U105/205.4 (V+), U201.4 (V+), VR101.3 (1), VR102.3 (1), VR201.3 (1), VR202.3 (1); also elsewhere on the board
-15V: C112.2, C116.2, C118.2, C212.2, D102.2 (A), D202.2 (A), R120.2, R126.1, R220.2, R226.2, U101.11 (V-), U104/204.6 (V-), U105/205.11 (V-), U201.11 (V-); also elsewhere on the board
/Channels A&B/OR: D107/207.3 (K), R150.1; also elsewhere on the board
GND: C111.2, C112.1, C113.2, C114.2, C115.2, C116.1, C117.2, C118.1, C211.2, C212.1, C213.2, R102.2, R103.2, R106.2, R110.1, R116.2, R123.1, R124.2, R127.1, R128.1, R132.2, R134.2, R135.2, R138.2, R141.2, R150.2, R202.2, R203.2, R206.2, R210.1, R216.2, R223.1, R224.2, R227.1, R228.1, R232.2, R234.2, R235.2, R238.2, R241.2, SW102.1 (A), U102.7 (VSS), U103/203.7 (VSS), U202.7 (VSS), VR101.1 (3), VR102.1 (3), VR201.1 (3), VR202.1 (3), VR203.1 (3); also elsewhere on the board
unnamed: C101.1, C_101.1, R136.1, R145.2, U101.7, U101.13 (-)
unnamed: C101.2, C_101.2, R131.2, U104/204.12
unnamed: C102.1, D104.2 (A), U101.14
unnamed: C102.2, D103.2 (A), R126.2, R128.2
unnamed: C103.2, D101.1 (A), R118.2
unnamed: C199.1, J101.1, R112.1, R199.1, SW101.3 (C)
unnamed: C199.2, D199.2 (A), R199.2
unnamed: C201.1, C_201.1, R236.1, R245.2, U201.8, U201.13 (-)
unnamed: C201.2, C_201.2, R231.2, U104/204.5
unnamed: C202.1, D204.2 (A), U201.14
unnamed: C202.2, D203.2 (A), R226.1, R228.2
unnamed: C203.2, D201.1 (A), R218.2
unnamed: C299.1, J201.1, R212.1, R299.1, SW201.3 (C)
unnamed: C299.2, D299.2 (A), R299.2
unnamed: D101.2 (A), D103.1 (K), R141.1, R142.2
unnamed: D101.3 (K), SW101.1 (A)
unnamed: D102.1 (K), Q102.2 (S)
unnamed: D104.1 (K), R133.2, R213.2
unnamed: D105.1 (K), Q103.3 (C)
unnamed: D106.1 (K), D206.2 (A)
unnamed: D107/207.1 (A), VR203.2
unnamed: D107/207.2 (A), J105.1, R140.1, R146.1, R147.1
unnamed: D108.1 (K), R144.2
unnamed: D108.2 (A), U105/205.8
unnamed: D109.1 (K), U102.10
unnamed: D109.2 (A), R111.1, R113.2
unnamed: D199.1 (K), R109.1, R112.2, SW101.2 (B)
unnamed: D201.2 (A), D203.1 (K), R241.1, R242.2
unnamed: D201.3 (K), SW201.1 (A)
unnamed: D202.1 (K), Q202.2 (S)
unnamed: D204.1 (K), R113.1, R233.2
unnamed: D205.1 (K), Q203.3 (C)
unnamed: D206.1 (K), R148.1
unnamed: D208.1 (K), R244.2
unnamed: D208.2 (A), U105/205.1
unnamed: D299.1 (K), R209.1, R212.2, SW201.2 (B)
unnamed: J102.1, R107.1
unnamed: J103.1, R117.1
unnamed: J104.1, R143.1, R144.1
unnamed: J202.1, R207.1
unnamed: J203.1, R217.1
unnamed: J204.1, R243.1, R244.1
unnamed: J205.1, R240.1, R246.1, R247.1, VR203.3 (1)
unnamed: Q101.1 (B2), R122.2, R123.2
unnamed: Q101.2 (B1), R106.1, U103/203.9, U103/203.10
unnamed: Q101.3 (C1), R129.2
unnamed: Q101.4 (E1), Q101.5 (E2), Q102.1 (D), R119.2
unnamed: Q101.6 (C2), Q102.3 (G), R120.1
unnamed: Q103.1 (B), R138.1, R140.2
unnamed: Q103.2 (E), R134.1
unnamed: Q201.1 (B2), R206.1, U103/203.2, U103/203.3
unnamed: Q201.2 (B1), R222.2, R223.2
unnamed: Q201.3 (C1), Q202.3 (G), R220.1
unnamed: Q201.4 (E1), Q201.5 (E2), Q202.1 (D), R219.2
unnamed: Q201.6 (C2), R229.2
unnamed: Q203.1 (B), R238.1, R240.2
unnamed: Q203.2 (E), R234.1
unnamed: R101.1, R102.1, U101.9 (-)
unnamed: R103.1, R109.2, R111.2, U101.10 (+)
unnamed: R104.2, R105.1, VR101.2
unnamed: R105.2, R107.2, R110.2, U103/203.8
unnamed: R108.1, U102.2, U102.6
unnamed: R108.2, U101.8
unnamed: R114.2, R115.1, VR102.2
unnamed: R115.2, R116.1, R117.2, U103/203.11
unnamed: R121.1, R125.2, R137.1, U101.1
unnamed: R121.2, U102.1
unnamed: R122.1, TR101.2
unnamed: R124.1, U104/204.14 (+)
unnamed: R125.1, R127.2, U104/204.13 (-)
unnamed: R129.1, U104/204.16
unnamed: R130.1, U101.3 (+)
unnamed: R130.2, U102.5, U102.11, U103/203.6
unnamed: R131.1, U101.6 (-)
unnamed: R132.1, U101.5 (+)
unnamed: R133.1, R135.1, R139.1, U101.12 (+)
unnamed: R136.2, R137.2, U101.2 (-)
unnamed: R142.1, U105/205.10 (+)
unnamed: R143.2, U105/205.9 (-)
unnamed: R145.1, U105/205.12 (+)
unnamed: R146.2, U105/205.13 (-)
unnamed: R147.2, U105/205.14
unnamed: R148.2, R149.2, SW102.2 (B)
unnamed: R149.1, U102.8, U202.2
unnamed: R201.1, R202.1, U201.6 (-)
unnamed: R203.1, R209.2, R211.2, U201.5 (+)
unnamed: R204.2, R205.1, VR201.2
unnamed: R205.2, R207.2, R210.2, U103/203.4
unnamed: R208.1, U202.6, U202.9
unnamed: R208.2, U201.7
unnamed: R211.1, U202.3
unnamed: R213.1, U202.1
unnamed: R214.2, R215.1, VR202.2
unnamed: R215.2, R216.1, R217.2, U103/203.1
unnamed: R221.1, R225.2, R237.1, U201.1
unnamed: R221.2, U202.8
unnamed: R222.1, TR201.2
unnamed: R224.1, U104/204.3 (+)
unnamed: R225.1, R227.2, U104/204.4 (-)
unnamed: R229.1, U104/204.1
unnamed: R230.1, U201.3 (+)
unnamed: R230.2, U103/203.5, U202.5, U202.11
unnamed: R231.1, U201.9 (-)
unnamed: R232.1, U201.10 (+)
unnamed: R233.1, R235.1, R239.1, U201.12 (+)
unnamed: R236.2, R237.2, U201.2 (-)
unnamed: R242.1, U105/205.3 (+)
unnamed: R243.2, U105/205.2 (-)
unnamed: R245.1, U105/205.5 (+)
unnamed: R246.2, U105/205.6 (-)
unnamed: R247.2, U105/205.7
unnamed: U102.4, U102.9, U102.12, U103/203.12
unnamed: U102.3, U102.13
unnamed: U103/203.13, U202.4, U202.12
unnamed: U202.10, U202.13

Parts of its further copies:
C301, C401: 220n; C_2416_6041Metric
C302, C303, C399, C402, C403, C499: 47n; C_0805_2012Metric
C311, C312, C313, C314, C315, C316, C317, C318, C411, C412, C413: 100n; C_0805_2012Metric
C_301, C_401: 220n; C_Rect_L7.0mm_W2.5mm_P5.00mm
D301, D307/407, D401: BAT54C; SOT-23
D302, D402: SZMM3Z10VST1G; D_SOD-323
D303, D304, D308, D309, D399, D403, D404, D408, D499: BAT54WS; D_SOD-323
D305, D405: Red_3mm; LED_D3.0mm
D306, D406: Yel_3mm; LED_D3.0mm
J301, J401: 108-0906-001; Johnson_108-09XX-001
J302, J303, J402, J403: 108-0903-001; Johnson_108-09XX-001
J304, J404: 108-0902-001; Johnson_108-09XX-001
J305, J405: 108-0910-001; Johnson_108-09XX-001
Q301, Q401: DMMT3906W; SOT-363_SC-70-6
Q302, Q402: MMBFJ201; SOT-23
Q303, Q403: MMBT3904; SOT-23
R301, R311, R312, R338, R341, R350, R401, R411, R412, R438, R441: 100k; R_0805_2012Metric
R302, R319, R329, R330, R331, R332, R402, R419, R429, R430, R431, R432: 4k7; R_0805_2012Metric
R303, R403: 15k; R_0805_2012Metric
R304, R308, R309, R313, R314, R321, R325, R349, R404, R408, R409, R413, R414, R421, R425: 47k; R_0805_2012Metric
R305, R307, R315, R317, R335, R405, R407, R415, R417, R435: 49k9; R_0805_2012Metric
R306, R348, R406: 5k6; R_0805_2012Metric
R310, R316, R344, R347, R410, R416, R444, R447: 1k; R_0805_2012Metric
R318, R320, R399, R418, R420, R499: 4M7; R_0805_2012Metric
R322, R422: 150k; R_0805_2012Metric
R323, R324, R327, R423, R424, R427: 680R; R_0805_2012Metric
R326, R336, R343, R346, R426, R436, R443, R446: 10k; R_0805_2012Metric
R328, R333, R340, R428, R433, R440: 22k; R_0805_2012Metric
R334, R434: 6k8; R_0805_2012Metric
R337, R437: 470k; R_0805_2012Metric
R339, R439: 1M; R_0805_2012Metric
R342, R345, R442, R445: 11k; R_0805_2012Metric
SW301, SW401: SPDT_ON-OFF-ON; M201xSS1x01
SW302: SPDT_ON-ON; M201xSS1x01
TR301, TR401: 50k; Potentiometer_Bourns_3314J_Vertical
U301, U305/405, U401: TL074; SOIC-14_3.9x8.7mm_P1.27mm
U302, U402: 4001; SOIC-14_3.9x8.7mm_P1.27mm
U303/403: 4066; SOIC-14_3.9x8.7mm_P1.27mm
U304/404: LM13700; SOIC-16_3.9x9.9mm_P1.27mm
VR301, VR302, VR401, VR402: 10kB; RV16AF-41-(L)R1-XXX
VR403: 100kB; RD901F-40-00D

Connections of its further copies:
+10V: C313.1, C314.1, C413.1, U302.14 (VDD), U303/403.14 (VDD), U402.14 (VDD); also elsewhere on the board
+12V: D305.2 (A), D306.2 (A), D405.2 (A); also elsewhere on the board
+15V: C303.1, C311.1, C315.1, C317.1, C403.1, C411.1, R301.2, R304.1, R314.1, R318.1, R319.1, R339.2, R401.2, R404.1, R414.1, R418.1, R419.1, R439.2, SW302.3 (C), TR301.1, TR401.1, U301.4 (V+), U304/404.11 (V+), U305/405.4 (V+), U401.4 (V+), VR301.3 (1), VR302.3 (1), VR401.3 (1), VR402.3 (1); also elsewhere on the board
-15V: C312.2, C316.2, C318.2, C412.2, D302.2 (A), D402.2 (A), R320.2, R326.1, R420.2, R426.2, U301.11 (V-), U304/404.6 (V-), U305/405.11 (V-), U401.11 (V-); also elsewhere on the board
/Channels C&D/OR: D307/407.3 (K), R350.1; also elsewhere on the board
GND: C311.2, C312.1, C313.2, C314.2, C315.2, C316.1, C317.2, C318.1, C411.2, C412.1, C413.2, R302.2, R303.2, R306.2, R310.1, R316.2, R323.1, R324.2, R327.1, R328.1, R332.2, R334.2, R335.2, R338.2, R341.2, R350.2, R402.2, R403.2, R406.2, R410.1, R416.2, R423.1, R424.2, R427.1, R428.1, R432.2, R434.2, R435.2, R438.2, R441.2, SW302.1 (A), U302.7 (VSS), U303/403.7 (VSS), U402.7 (VSS), VR301.1 (3), VR302.1 (3), VR401.1 (3), VR402.1 (3), VR403.1 (3); also elsewhere on the board
unnamed: C301.1, C_301.1, R336.1, R345.2, U301.7, U301.13 (-)
unnamed: C301.2, C_301.2, R331.2, U304/404.12
unnamed: C302.1, D304.2 (A), U301.14
unnamed: C302.2, D303.2 (A), R326.2, R328.2
unnamed: C303.2, D301.1 (A), R318.2
unnamed: C399.1, J301.1, R312.1, R399.1, SW301.3 (C)
unnamed: C399.2, D399.2 (A), R399.2
unnamed: C401.1, C_401.1, R436.1, R445.2, U401.8, U401.13 (-)
unnamed: C401.2, C_401.2, R431.2, U304/404.5
unnamed: C402.1, D404.2 (A), U401.14
unnamed: C402.2, D403.2 (A), R426.1, R428.2
unnamed: C403.2, D401.1 (A), R418.2
unnamed: C499.1, J401.1, R412.1, R499.1, SW401.3 (C)
unnamed: C499.2, D499.2 (A), R499.2
unnamed: D301.2 (A), D303.1 (K), R341.1, R342.2
unnamed: D301.3 (K), SW301.1 (A)
unnamed: D302.1 (K), Q302.2 (S)
unnamed: D304.1 (K), R333.2, R413.2
unnamed: D305.1 (K), Q303.3 (C)
unnamed: D306.1 (K), D406.2 (A)
unnamed: D307/407.1 (A), VR403.2
unnamed: D307/407.2 (A), J305.1, R340.1, R346.1, R347.1
unnamed: D308.1 (K), R344.2
unnamed: D308.2 (A), U305/405.8
unnamed: D309.1 (K), U302.10
unnamed: D309.2 (A), R311.1, R313.2
unnamed: D399.1 (K), R309.1, R312.2, SW301.2 (B)
unnamed: D401.2 (A), D403.1 (K), R441.1, R442.2
unnamed: D401.3 (K), SW401.1 (A)
unnamed: D402.1 (K), Q402.2 (S)
unnamed: D404.1 (K), R313.1, R433.2
unnamed: D405.1 (K), Q403.3 (C)
unnamed: D406.1 (K), R348.1
unnamed: D408.1 (K), R444.2
unnamed: D408.2 (A), U305/405.1
unnamed: D499.1 (K), R409.1, R412.2, SW401.2 (B)
unnamed: J302.1, R307.1
unnamed: J303.1, R317.1
unnamed: J304.1, R343.1, R344.1
unnamed: J402.1, R407.1
unnamed: J403.1, R417.1
unnamed: J404.1, R443.1, R444.1
unnamed: J405.1, R440.1, R446.1, R447.1, VR403.3 (1)
unnamed: Q301.1 (B2), R322.2, R323.2
unnamed: Q301.2 (B1), R306.1, U303/403.9, U303/403.10
unnamed: Q301.3 (C1), R329.2
unnamed: Q301.4 (E1), Q301.5 (E2), Q302.1 (D), R319.2
unnamed: Q301.6 (C2), Q302.3 (G), R320.1
unnamed: Q303.1 (B), R338.1, R340.2
unnamed: Q303.2 (E), R334.1
unnamed: Q401.1 (B2), R406.1, U303/403.2, U303/403.3
unnamed: Q401.2 (B1), R422.2, R423.2
unnamed: Q401.3 (C1), Q402.3 (G), R420.1
unnamed: Q401.4 (E1), Q401.5 (E2), Q402.1 (D), R419.2
unnamed: Q401.6 (C2), R429.2
unnamed: Q403.1 (B), R438.1, R440.2
unnamed: Q403.2 (E), R434.1
unnamed: R301.1, R302.1, U301.9 (-)
unnamed: R303.1, R309.2, R311.2, U301.10 (+)
unnamed: R304.2, R305.1, VR301.2
unnamed: R305.2, R307.2, R310.2, U303/403.8
unnamed: R308.1, U302.2, U302.6
unnamed: R308.2, U301.8
unnamed: R314.2, R315.1, VR302.2
unnamed: R315.2, R316.1, R317.2, U303/403.11
unnamed: R321.1, R325.2, R337.1, U301.1
unnamed: R321.2, U302.1
unnamed: R322.1, TR301.2
unnamed: R324.1, U304/404.14 (+)
unnamed: R325.1, R327.2, U304/404.13 (-)
unnamed: R329.1, U304/404.16
unnamed: R330.1, U301.3 (+)
unnamed: R330.2, U302.5, U302.11, U303/403.6
unnamed: R331.1, U301.6 (-)
unnamed: R332.1, U301.5 (+)
unnamed: R333.1, R335.1, R339.1, U301.12 (+)
unnamed: R336.2, R337.2, U301.2 (-)
unnamed: R342.1, U305/405.10 (+)
unnamed: R343.2, U305/405.9 (-)
unnamed: R345.1, U305/405.12 (+)
unnamed: R346.2, U305/405.13 (-)
unnamed: R347.2, U305/405.14
unnamed: R348.2, R349.2, SW302.2 (B)
unnamed: R349.1, U302.8, U402.2
unnamed: R401.1, R402.1, U401.6 (-)
unnamed: R403.1, R409.2, R411.2, U401.5 (+)
unnamed: R404.2, R405.1, VR401.2
unnamed: R405.2, R407.2, R410.2, U303/403.4
unnamed: R408.1, U402.6, U402.9
unnamed: R408.2, U401.7
unnamed: R411.1, U402.3
unnamed: R413.1, U402.1
unnamed: R414.2, R415.1, VR402.2
unnamed: R415.2, R416.1, R417.2, U303/403.1
unnamed: R421.1, R425.2, R437.1, U401.1
unnamed: R421.2, U402.8
unnamed: R422.1, TR401.2
unnamed: R424.1, U304/404.3 (+)
unnamed: R425.1, R427.2, U304/404.4 (-)
unnamed: R429.1, U304/404.1
unnamed: R430.1, U401.3 (+)
unnamed: R430.2, U303/403.5, U402.5, U402.11
unnamed: R431.1, U401.9 (-)
unnamed: R432.1, U401.10 (+)
unnamed: R433.1, R435.1, R439.1, U401.12 (+)
unnamed: R436.2, R437.2, U401.2 (-)
unnamed: R442.1, U305/405.3 (+)
unnamed: R443.2, U305/405.2 (-)
unnamed: R445.1, U305/405.5 (+)
unnamed: R446.2, U305/405.6 (-)
unnamed: R447.2, U305/405.7
unnamed: U302.4, U302.9, U302.12, U303/403.12
unnamed: U302.3, U302.13
unnamed: U303/403.13, U402.4, U402.12
unnamed: U402.10, U402.13

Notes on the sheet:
Unused Gates
Gate to trig option Do not populate
Power Filtering
Input Amplifier and Logic
Integrator, Level Detectors and Output Amplifiers

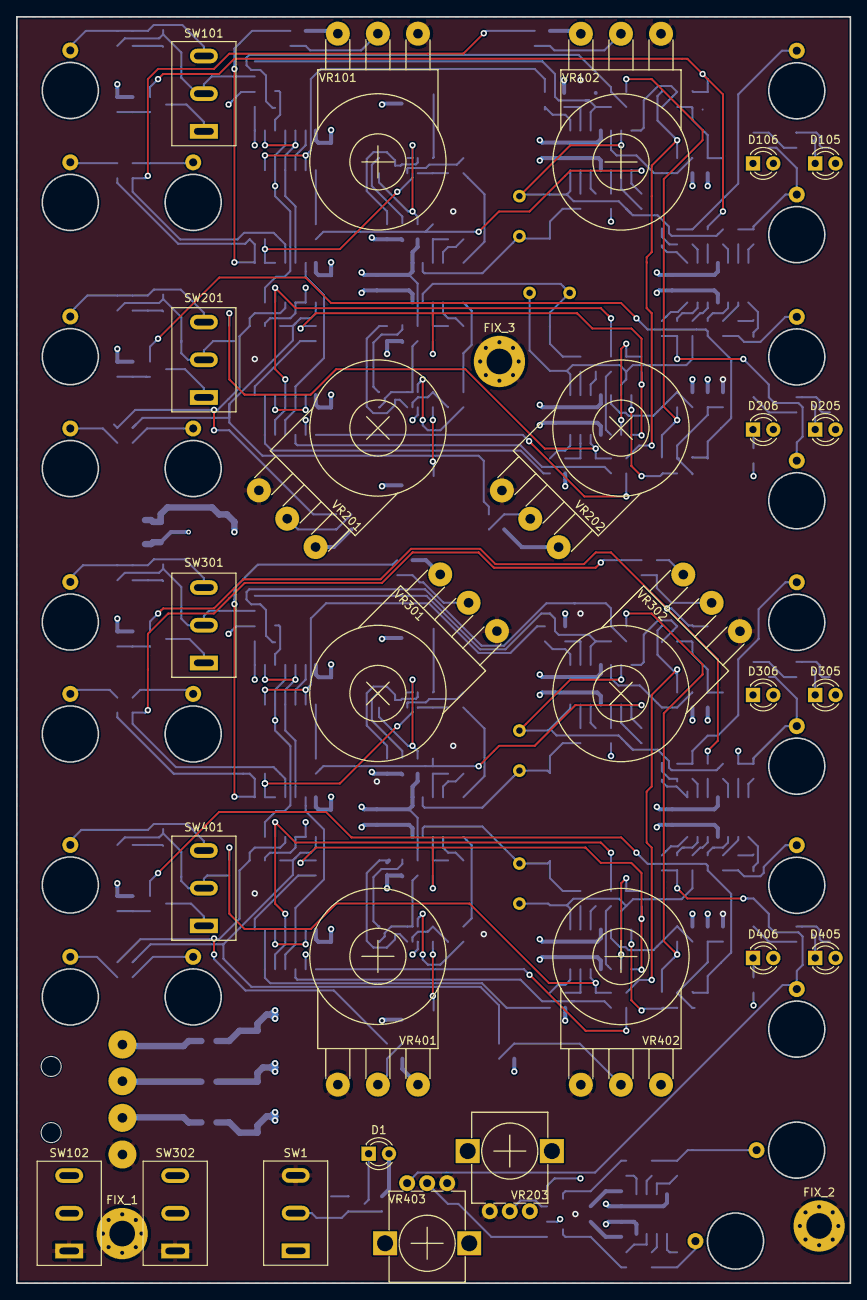
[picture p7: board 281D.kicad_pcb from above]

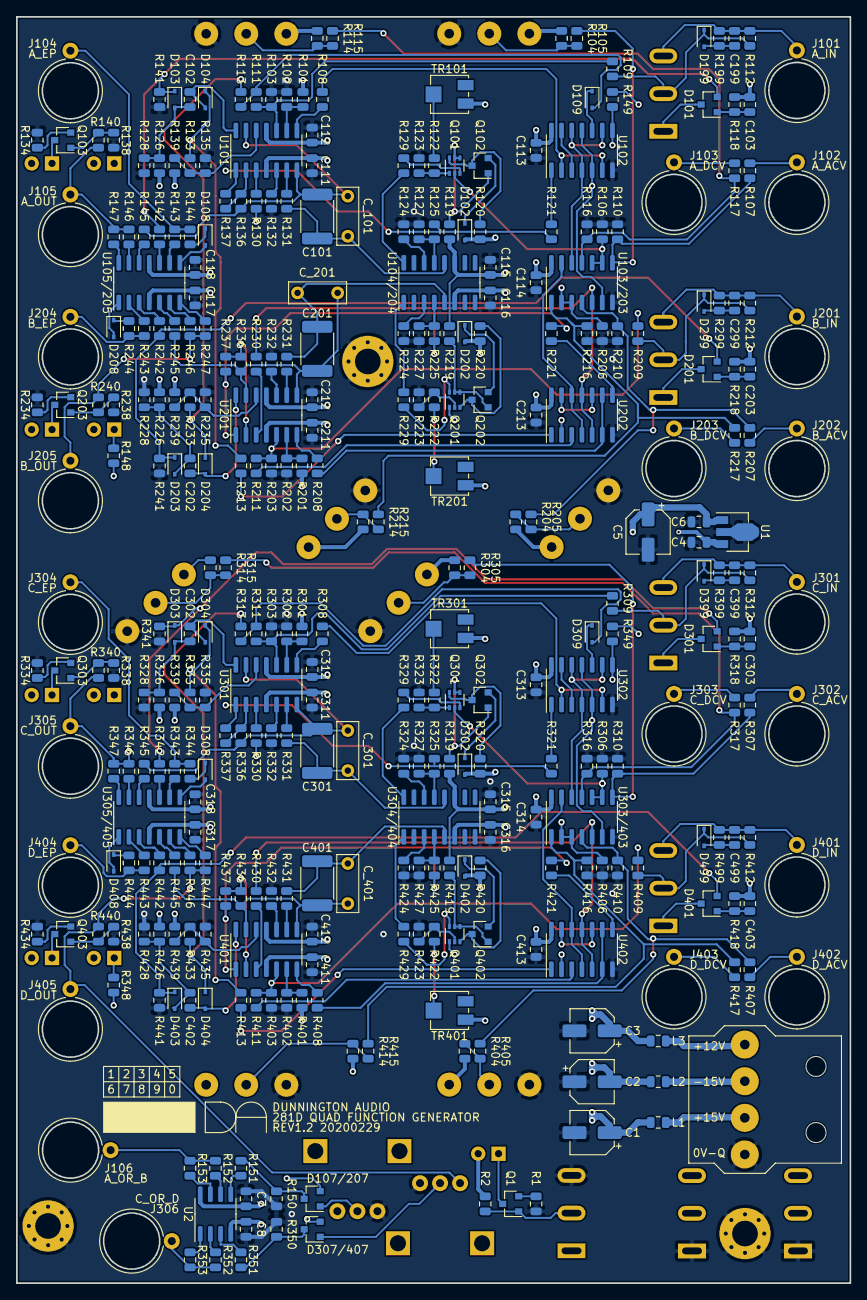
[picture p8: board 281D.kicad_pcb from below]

Board: 4 copper layers, 104.0 x 158.0 mm, 380 parts (351 on the bottom side), 251 nets.

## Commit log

2020-05-19 Update .gitignore, update BOM, add BOM pdf.
    [281D_Master_BOM.ods]
2020-06-10 Update BOM, BOM pdf, notes. Schematic and assembly guide correction.
    [281D.kicad_pcb, 281D.sch, 281D_Master_BOM.ods]
2020-06-29 Update BOM, BOM pdf, notes
    [281D_Master_BOM.ods]
